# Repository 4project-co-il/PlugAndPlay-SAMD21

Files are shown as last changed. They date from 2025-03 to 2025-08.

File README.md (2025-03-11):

# PlugAndPlay: SAMD21 Dev Board
This is the repository with the files for PlugAndPlay SAMD21 Development Board.

The PlugAndPlay system is an arduino-based environment that allows easier connections between the parts
and intended to create a more "product-like" projects with permanent connections, compared to a breadboard.

PlugAndPlay parts do not require any soldering to connect. Just plug the cable to the connectors and you are ready to go.
In the worst case, you might need to tighten few screws on a terminal block.

Most of the parts in the PlugAndPlay system communicate via I2C protocol. 
The connectors between the parts have 6 lines: 2 lines to provide the power (3.3V VCC and GND), 2 lines for the I2C communication and additional 2 lines for the interrupts, that can be used as digital inputs or outputs in some cases.
The interrupts are handled by the Event Based Framework ([EBF](https://github.com/4project-co-il/EBF)) in the background. No polling is needed in the software.
A button pressed? Event function will be called in your code to handle that change.

Using the interrupts allows creation of very low-power projects, as well as controllers with fast responding to changes.
The PlugAndPlay SAMD21 Dev Board consumes only 21.5 uA in deep sleep. Yes, 21.5 micro-amper!
The system is designed to work with 3.3V power supply, but can go down to about 2V as well, so even less power consumption is possible for very low power needs.

No need to worry about the correct wires connection, accidental inversion of I2C lines, or even worse, the VCC and GND.
No need to worry about the I2C addresses as well. Pull-up resistors if you connect few parts in serial, are those needed or not?
What port should I connect the part? Is is PWM complatible? No more wories like that.
Just plug the connectors and start playing with the code. As easy as that.

Every PlugAndPlay device contains an EEPROM with its identification, that allows the PnP code to match between the code instance implementing a logic to the physical device connected to one of the PnP ports on the SAMD21 Dev Board.

Communication is not the only thing handled by the PnP system. Power distribution is easily managed as well.
Need to have a 12V relay, 5V servo and 3.3V for the logic? No problem at all...
Plug the power cables between the parts, add needed regulator to the board and you're done.

The board is manufactured by the [4project.co.il](https://www.4project.co.il/).\
You will need the Event Based Framework ([EBF](https://github.com/4project-co-il/EBF)) to program the board.

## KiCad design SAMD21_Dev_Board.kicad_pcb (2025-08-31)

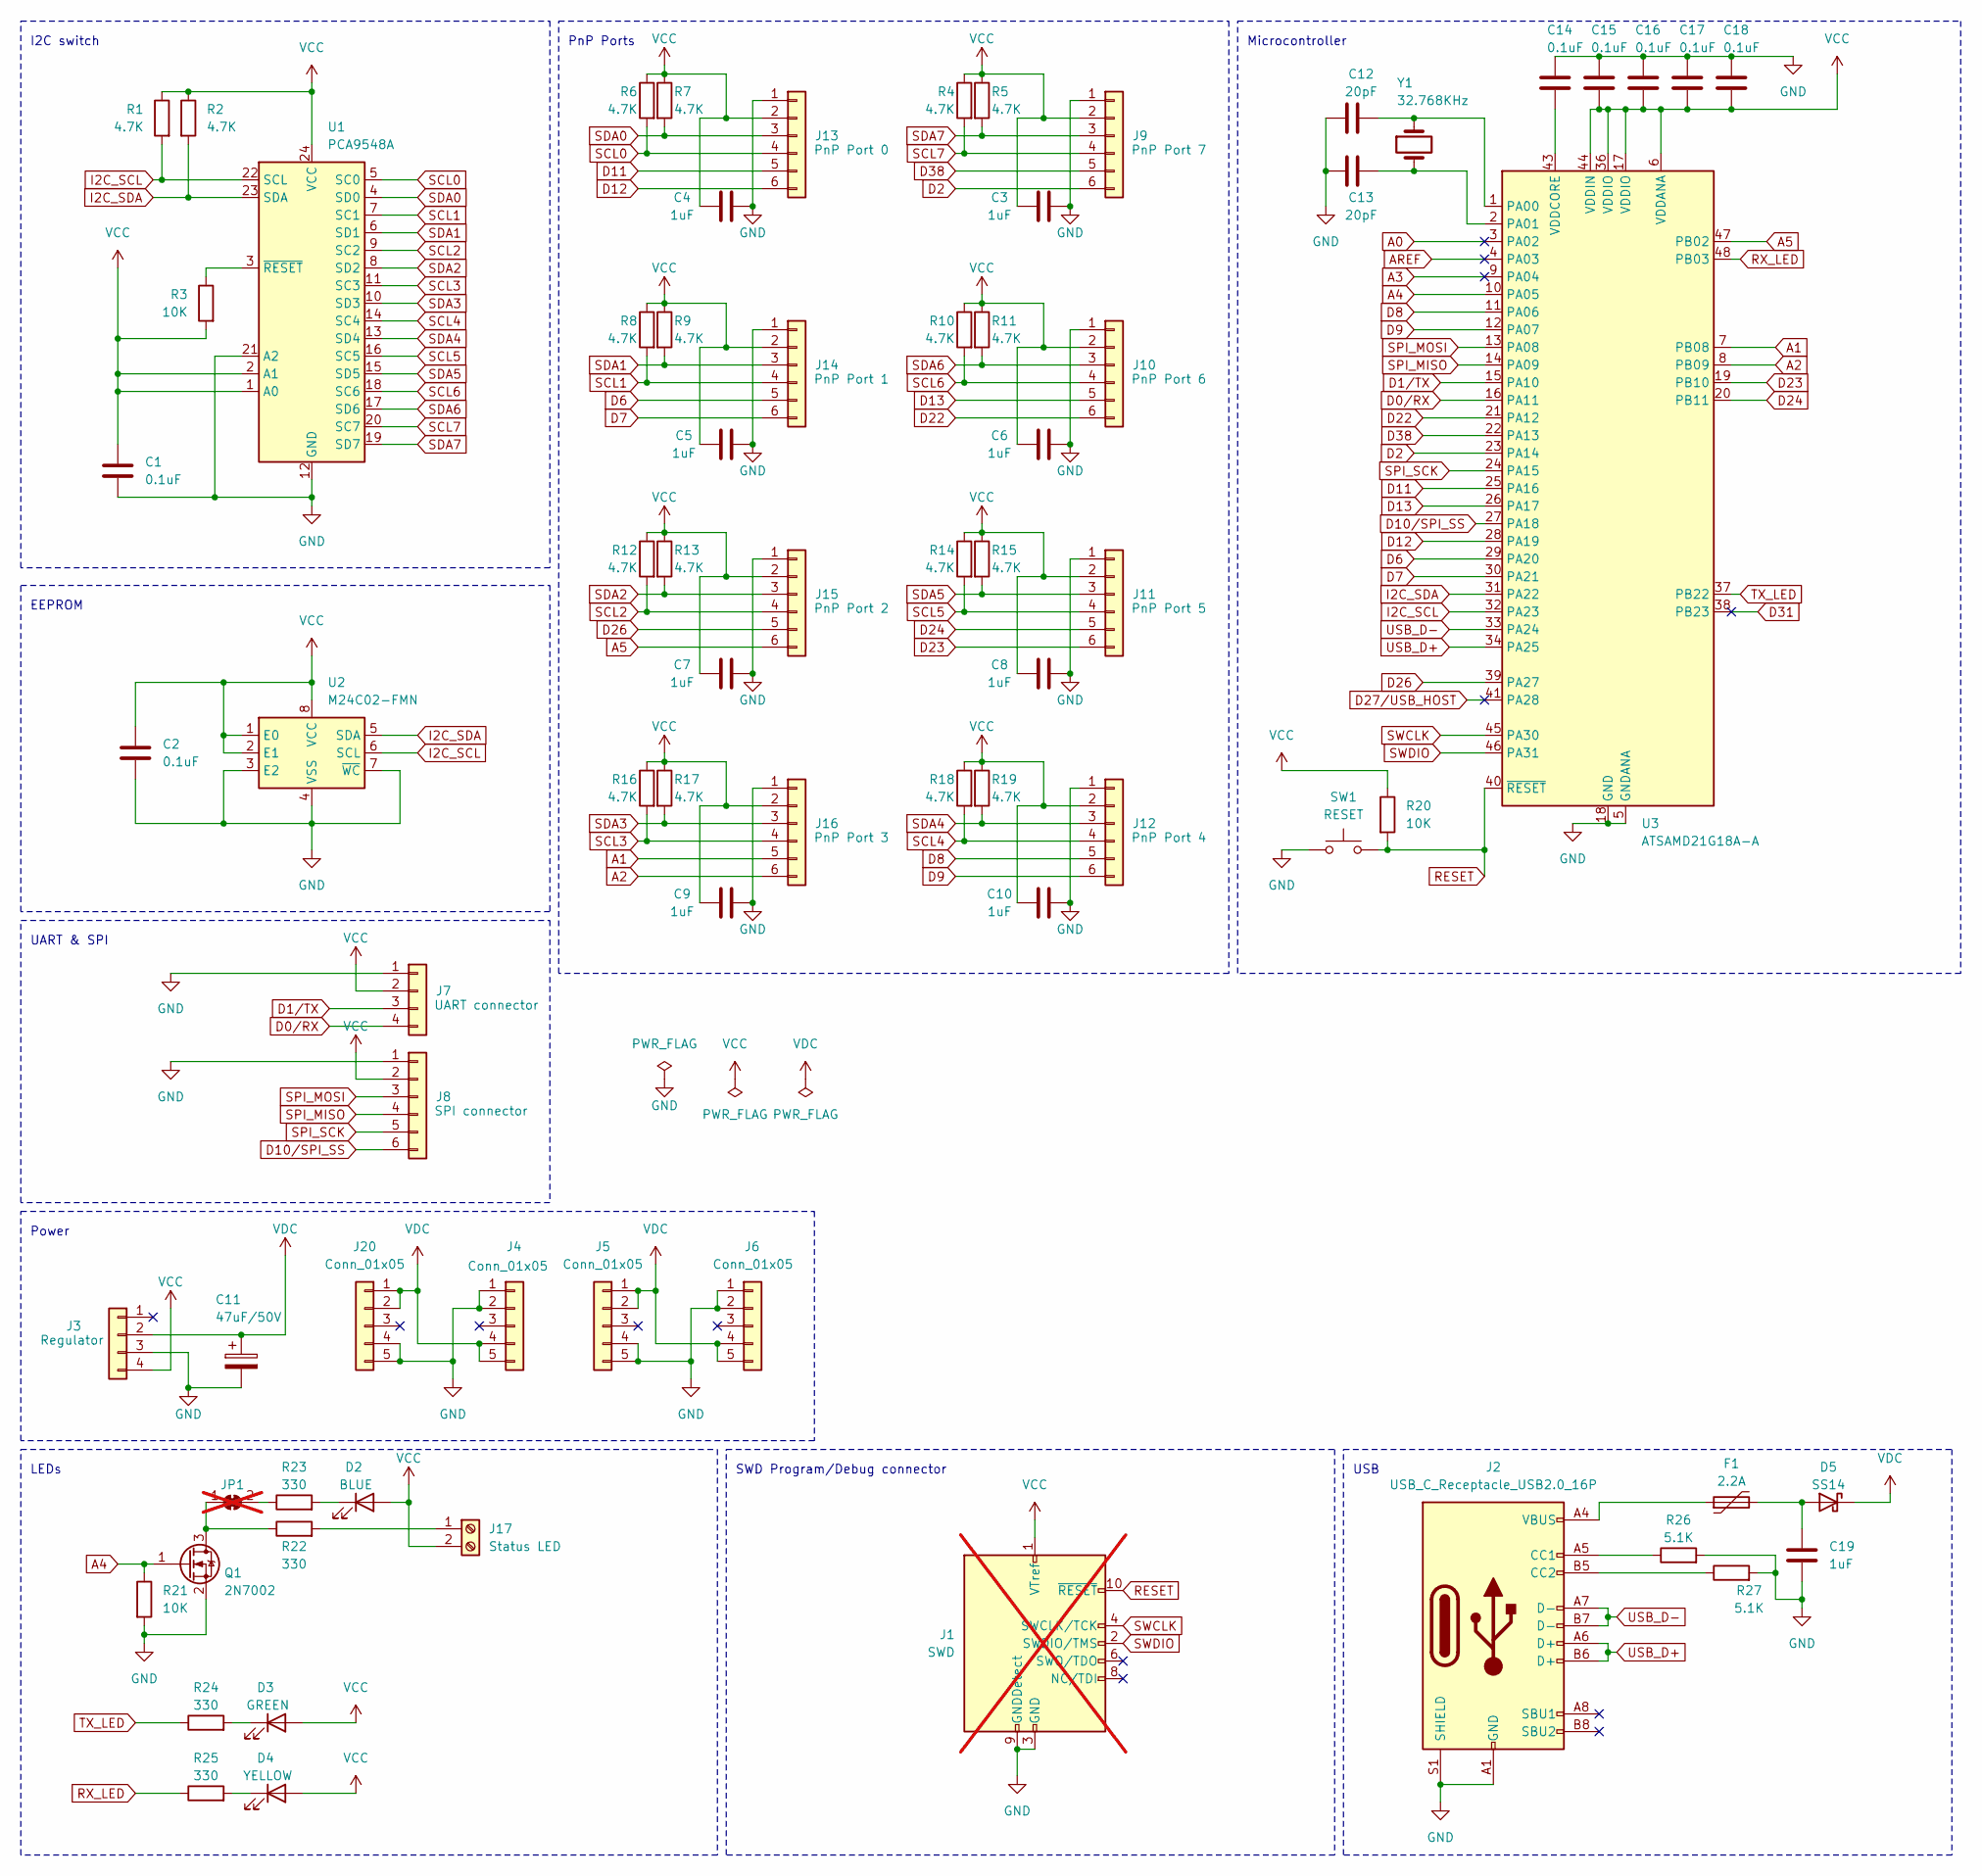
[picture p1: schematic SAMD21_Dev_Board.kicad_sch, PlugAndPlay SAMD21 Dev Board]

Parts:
C1, C2, C14, C15, C16, C17, C18: 0.1uF; C_0603_1608Metric; MPN C14663
C3, C4, C5, C6, C7, C8, C9, C10, C19: 1uF; C_0603_1608Metric; MPN C1592
C11: 47uF/50V; C_Elec_6.3x7.7; MPN C3349
C12, C13: 20pF; C_0603_1608Metric; MPN C105621
D2: BLUE; LED_0603_1608Metric; MPN C965807
D3: GREEN; LED_0603_1608Metric; MPN C965804
D4: YELLOW; LED_0603_1608Metric; MPN C965802
D5: SS14; D_SMA; MPN C2480
F1: 2.2A; Fuse_1206_3216Metric; MPN C89654
J1: SWD; PinHeader_2x05_P1.27mm_Vertical; not fitted
J2: USB_C_Receptacle_USB2.0_16P; USB_C_Receptacle_G-Switch_GT-USB-7010ASV; MPN C2988369
J3: PinSocket_1x04_P2.54mm_Vertical_SMD_Pin1Left; MPN C20071191
J4, J6: Conn_01x05; PinSocket_1x05_P2.54mm_Vertical_SMD_Pin1Left; MPN RealRun
J5, J20: Conn_01x05; PinSocket_1x05_P2.54mm_Vertical_SMD_Pin1Right; MPN RealRun
J7: JST_SH_SM04B-SRSS-TB_1x04-1MP_P1.00mm_Horizontal; MPN C7430446
J8, J9, J10, J11, J12, J13, J14, J15, J16: JST_SH_SM06B-SRSS-TB_1x06-1MP_P1.00mm_Horizontal; MPN C7430448
J17: Status LED; TerminalBlock_TE_282834-2_1x02_P2.54mm_Horizontal; MPN C695629
JP1: SolderJumper_2_Bridged; SolderJumper-2_P1.3mm_Bridged_RoundedPad1.0x1.5mm; not fitted
Q1: 2N7002; SOT-23; MPN C916396
R1, R2, R4, R5, R6, R7, R8, R9, R10, R11, R12, R13, R14, R15, R16, R17, R18, R19: 4.7K; R_0603_1608Metric; MPN C23162
R3, R20, R21: 10K; R_0603_1608Metric; MPN C25804
R22, R23, R24, R25: 330; R_0603_1608Metric; MPN C23138
R26, R27: 5.1K; R_0603_1608Metric; MPN C23186
SW1: RESET; SW_Push_1P1T_XKB_TS-1187A; MPN C318884
U1: PCA9548A; TSSOP-24_4.4x7.8mm_P0.65mm; MPN C295762
U2: M24C02-FMN; SOIC-8_3.9x4.9mm_P1.27mm; MPN C114502
U3: ATSAMD21G18A-A; TQFP-48_7x7mm_P0.5mm; MPN C78624
Y1: 32.768KHz; Crystal_SMD_3215-2Pin_3.2x1.5mm; MPN C620155

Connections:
A0: U3.3 (PA02)
A1: J16.5, U3.7 (PB08)
A2: J16.6, U3.8 (PB09)
A3: U3.9 (PA04)
A4: Q1.1 (G), R21.1, U3.10 (PA05)
A5: J15.6, U3.47 (PB02)
AREF: U3.4 (PA03)
D0/RX: J7.4, U3.16 (PA11)
D1/TX: J7.3, U3.15 (PA10)
D2: J9.6, U3.23 (PA14)
D6: J14.5, U3.29 (PA20)
D7: J14.6, U3.30 (PA21)
D8: J12.5, U3.11 (PA06)
D9: J12.6, U3.12 (PA07)
D10/SPI_SS: J8.6, U3.27 (PA18)
D11: J13.5, U3.25 (PA16)
D12: J13.6, U3.28 (PA19)
D13: J10.5, U3.26 (PA17)
D22: J10.6, U3.21 (PA12)
D23: J11.6, U3.19 (PB10)
D24: J11.5, U3.20 (PB11)
D26: J15.5, U3.39 (PA27)
D27/USB_HOST: U3.41 (PA28)
D31: U3.38 (PB23)
D38: J9.5, U3.22 (PA13)
GND: C1.2, C2.2, C3.1, C4.1, C5.2, C6.1, C7.1, C8.1, C9.1, C10.1, C11.2, C12.1, C13.1, C14.1, C15.1, C16.1, C17.1, C18.1, C19.2, J1.3 (GND), J1.5 (GND), J1.9 (GNDDetect), J2.A1 (GND), J2.A12 (GND), J2.B1 (GND), J2.B12 (GND), J2.S1 (SHIELD), J3.3, J4.1, J4.2, J5.4, J5.5, J6.1, J6.2, J7.1, J8.1, J9.1, J10.1, J11.1, J12.1, J13.1, J14.1, J15.1, J16.1, J20.4, J20.5, Q1.2 (S), R21.2, R26.2, R27.2, SW1.1, U1.12 (GND), U1.21 (A2), U2.3 (E2), U2.4 (VSS), U2.7 (~WC), U3.5 (GNDANA), U3.18 (GND), U3.35 (GND), U3.42 (GND)
I2C_SCL: R1.2, U1.22 (SCL), U2.6 (SCL), U3.32 (PA23)
I2C_SDA: R2.2, U1.23 (SDA), U2.5 (SDA), U3.31 (PA22)
unnamed: D2.1 (K), R23.2
unnamed: D3.1 (K), R24.2
unnamed: D4.1 (K), R25.2
unnamed: C19.1, D5.2 (A), F1.2
unnamed: F1.1, J2.A4 (VBUS), J2.A9 (VBUS), J2.B4 (VBUS), J2.B9 (VBUS)
unnamed: J2.A5 (CC1), R26.1
unnamed: J2.B5 (CC2), R27.1
unnamed: J17.1, R22.2
unnamed: JP1.1 (A), Q1.3 (D), R22.1
unnamed: JP1.2 (B), R23.1
unnamed: R3.1, U1.3 (~RESET)
unnamed: C12.2, U3.1 (PA00), Y1.1
unnamed: C13.2, U3.2 (PA01), Y1.2
unnamed: C14.2, U3.43 (VDDCORE)
RESET: J1.10 (~RESET), R20.2, SW1.2, U3.40 (~RESET)
RX_LED: R25.1, U3.48 (PB03)
SCL0: J13.4, R6.2, U1.5 (SC0)
SCL1: J14.4, R8.2, U1.7 (SC1)
SCL2: J15.4, R12.2, U1.9 (SC2)
SCL3: J16.4, R16.2, U1.11 (SC3)
SCL4: J12.4, R18.2, U1.14 (SC4)
SCL5: J11.4, R14.2, U1.16 (SC5)
SCL6: J10.4, R10.2, U1.18 (SC6)
SCL7: J9.4, R4.2, U1.20 (SC7)
SDA0: J13.3, R7.2, U1.4 (SD0)
SDA1: J14.3, R9.2, U1.6 (SD1)
SDA2: J15.3, R13.2, U1.8 (SD2)
SDA3: J16.3, R17.2, U1.10 (SD3)
SDA4: J12.3, R19.2, U1.13 (SD4)
SDA5: J11.3, R15.2, U1.15 (SD5)
SDA6: J10.3, R11.2, U1.17 (SD6)
SDA7: J9.3, R5.2, U1.19 (SD7)
SPI_MISO: J8.4, U3.14 (PA09)
SPI_MOSI: J8.3, U3.13 (PA08)
SPI_SCK: J8.5, U3.24 (PA15)
SWCLK: J1.4 (SWCLK/TCK), U3.45 (PA30)
SWDIO: J1.2 (SWDIO/TMS), U3.46 (PA31)
TX_LED: R24.1, U3.37 (PB22)
USB_D+: J2.A6 (D+), J2.B6 (D+), U3.34 (PA25)
USB_D-: J2.A7 (D-), J2.B7 (D-), U3.33 (PA24)
VCC: C1.1, C2.1, C3.2, C4.2, C5.1, C6.2, C7.2, C8.2, C9.2, C10.2, C15.2, C16.2, C17.2, C18.2, D2.2 (A), D3.2 (A), D4.2 (A), J1.1 (VTref), J3.4, J7.2, J8.2, J9.2, J10.2, J11.2, J12.2, J13.2, J14.2, J15.2, J16.2, J17.2, R1.1, R2.1, R3.2, R4.1, R5.1, R6.1, R7.1, R8.1, R9.1, R10.1, R11.1, R12.1, R13.1, R14.1, R15.1, R16.1, R17.1, R18.1, R19.1, R20.1, U1.1 (A0), U1.2 (A1), U1.24 (VCC), U2.1 (E0), U2.2 (E1), U2.8 (VCC), U3.6 (VDDANA), U3.17 (VDDIO), U3.36 (VDDIO), U3.44 (VDDIN)
VDC: C11.1, D5.1 (K), J3.2, J4.4, J4.5, J5.1, J5.2, J6.4, J6.5, J20.1, J20.2

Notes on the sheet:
Microcontroller
USB
Power
PnP Ports
LEDs
UART & SPI
I2C switch
SWD Program/Debug connector
EEPROM

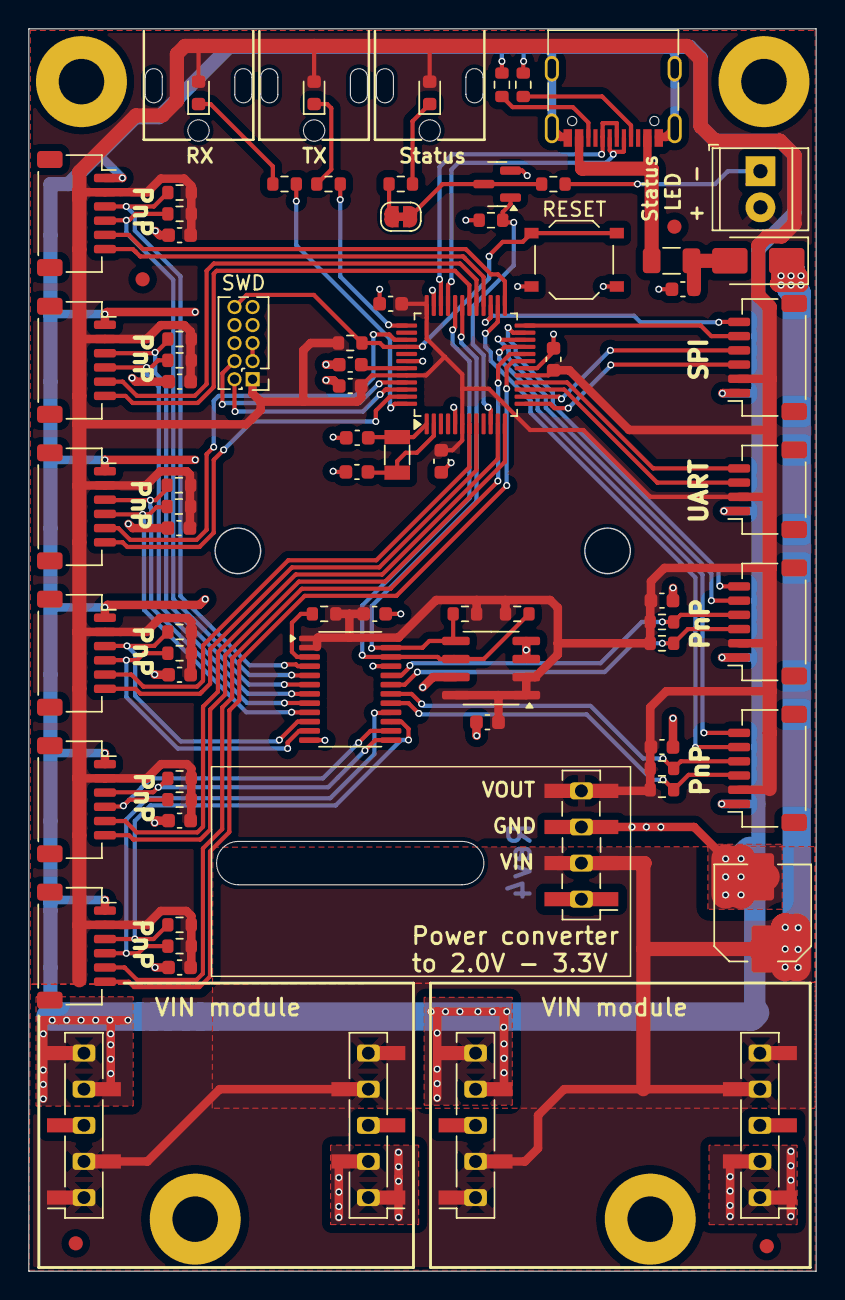
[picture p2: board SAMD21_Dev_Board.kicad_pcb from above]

Board: 2 copper layers, 55.4 x 87.4 mm, 76 parts (0 on the bottom side), 65 nets.

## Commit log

2025-01-19 Initial upload
    [SAMD21_Dev_Board-B_Cu.gbl, SAMD21_Dev_Board-B_Mask.gbs, SAMD21_Dev_Board-B_Paste.gbp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]
2025-02-07 Update gitignore
    [SAMD21_Dev_Board-B_Cu.gbl, SAMD21_Dev_Board-B_Mask.gbs, SAMD21_Dev_Board-B_Paste.gbp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]
2025-02-07 SWD port moved closer to the edge to be able use the pogo pins clip
    [SAMD21_Dev_Board.kicad_pcb, SAMD21_Dev_Board.kicad_sch]
2025-02-09 Minor cosmetic trace routing changes
    [SAMD21_Dev_Board.kicad_pcb]
2025-02-12 Fiducials change to 1mm footprint Using D4 line for status LED (can do PWM) instead of D13 Bootloader updated accordingly
    [SAMD21_Dev_Board.kicad_pcb, SAMD21_Dev_Board.kicad_sch]
2025-03-10 Power modules are set wider, to have more space for XT30 connectors. Interrupt lines were changed based on the SAMD21 interrupt mapping. PnP connector lines were swapped to match colors on the JST-SH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
    [SAMD21_Dev_Board.kicad_pcb, SAMD21_Dev_Board.kicad_sch]
2025-03-10 Kikit panelization
    [SAMD21_Dev_Board.csv, SAMD21_Dev_Board.kicad_pcb, SAMD21_Dev_Board.kicad_sch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]
2025-03-30 Adding missing holes on the bottom side. Adding holes in the middle of the board for potential add-ons.
    [SAMD21_Dev_Board.kicad_pcb]
2025-04-29 Added thermal relief
    [SAMD21_Dev_Board.kicad_pcb]
2025-05-11 Adding colors to GND,VCC and VDC nets. VIAs review.
    [SAMD21_Dev_Board.kicad_pcb]
2025-05-11 Reset line adjustment
    [SAMD21_Dev_Board.kicad_pcb]
2025-05-18 Back to cables with GND pin1, VCC pin2
    [SAMD21_Dev_Board.kicad_pcb, SAMD21_Dev_Board.kicad_sch]
2025-07-18 Moved the power modules location to have 1mm more spacing between them
    [SAMD21_Dev_Board.kicad_pcb]
2025-07-20 Adding Rev number to the back copper layer
    [SAMD21_Dev_Board.kicad_pcb]
2025-07-24 Ground plane return paths improvements
    [SAMD21_Dev_Board.kicad_pcb]
2025-08-31 Increase solder paste opennings by 5% for elect.capacitor and headers. Decrease screw terminal holes from 1.1mm to 1.0mm.
    [SAMD21_Dev_Board.kicad_pcb]
2026-01-11 Chanigng I2C mux and EEPROM I2C addresses to 0x01
2026-08-02 Library settings update after moving to KiCad9
2026-08-03 Change label "VIN module" to "PnP Power Module" Change cutout and holes to 2mm Adapt to Kicad9
2026-08-04 Holes and cutouts reduced to match M2 spacers. Removed thermal relief from the copper zones.
2026-08-10 All I2C channel's pull-up resistors removed, since connected devices will have their own
2026-09-22 Increase clearance for USB connector and big capacitor to the board edge, to allow using depaneling machine. Change headers footprint to be used from global FootprintLibrary.
2026-10-14 Update BOM export parameters
2026-11-03 Add holes of the LED CBI to user.Drawing layer, so those will be transfered to panel with kikit
